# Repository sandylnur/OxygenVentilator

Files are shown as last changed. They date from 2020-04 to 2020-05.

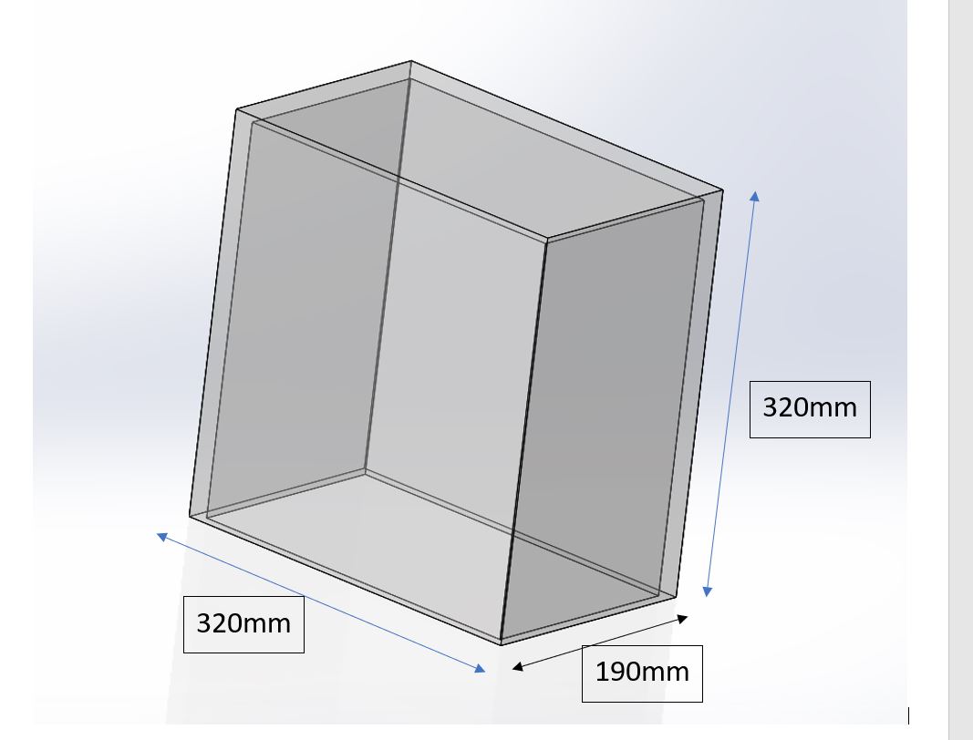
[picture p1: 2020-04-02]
ProtoType Deisgn/Casing Design & Dimensions/Approximate Require Casing Size.JPG

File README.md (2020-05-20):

# OxygenVentilator
The following is an initiative to cope for the lack of Oxygen Ventilator for the Covid-19 Outbreak. This is an Arduino based project for controlling an actuator/stepper motor.

Link to Doc
https://docs.google.com/document/d/1eH-yhwD40MbvZu5IXgRE8FFyR08LFT27kJvr4FsMqDs/edit?usp=sharing

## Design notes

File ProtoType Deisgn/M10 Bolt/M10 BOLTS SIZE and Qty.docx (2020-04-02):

# For Connection

M10 Bolts + Nuts will be used

Length(approximate) | Qty
43mm | 1
34mm | 1
84mm | 3

Washer for M10, Qty =6

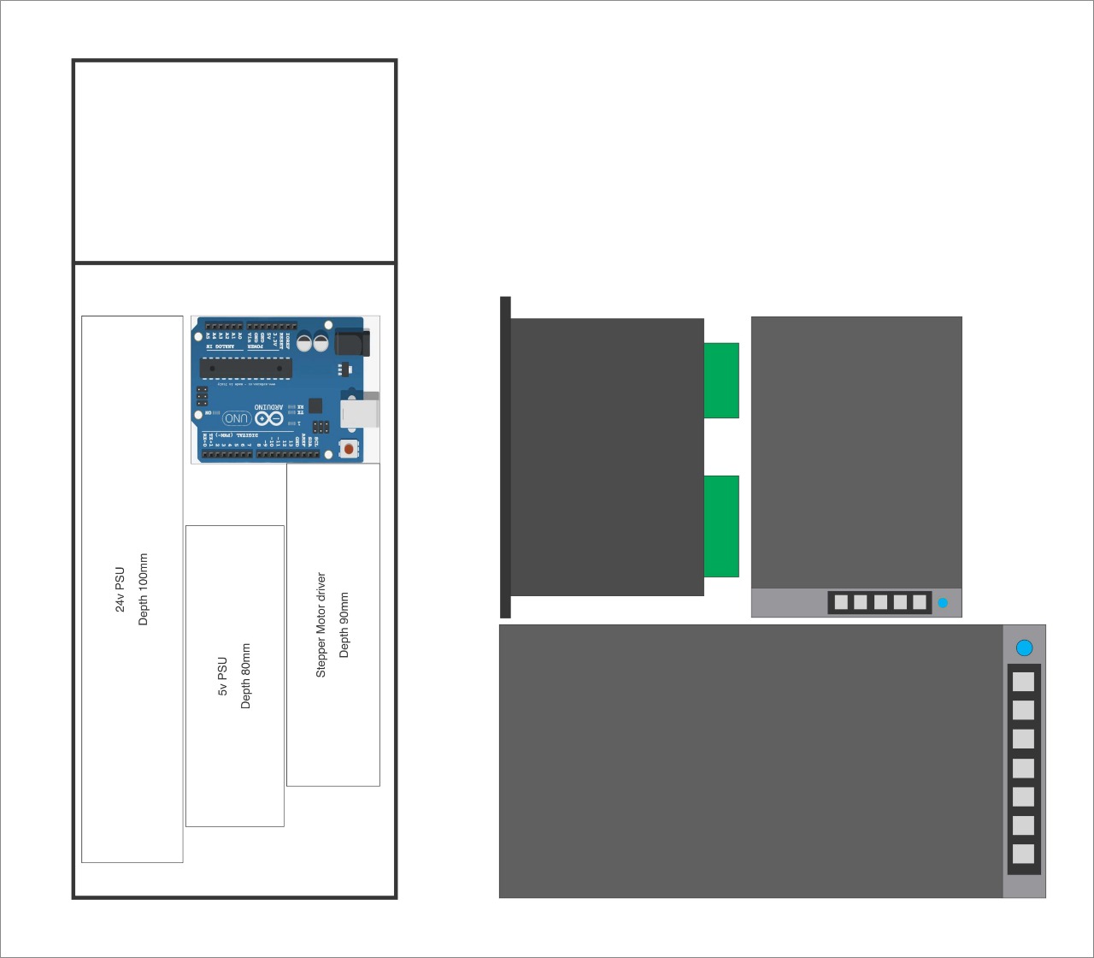
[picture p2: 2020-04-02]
ProtoType Deisgn/Casing Design & Dimensions/Electronics Placement Schematic.jpg

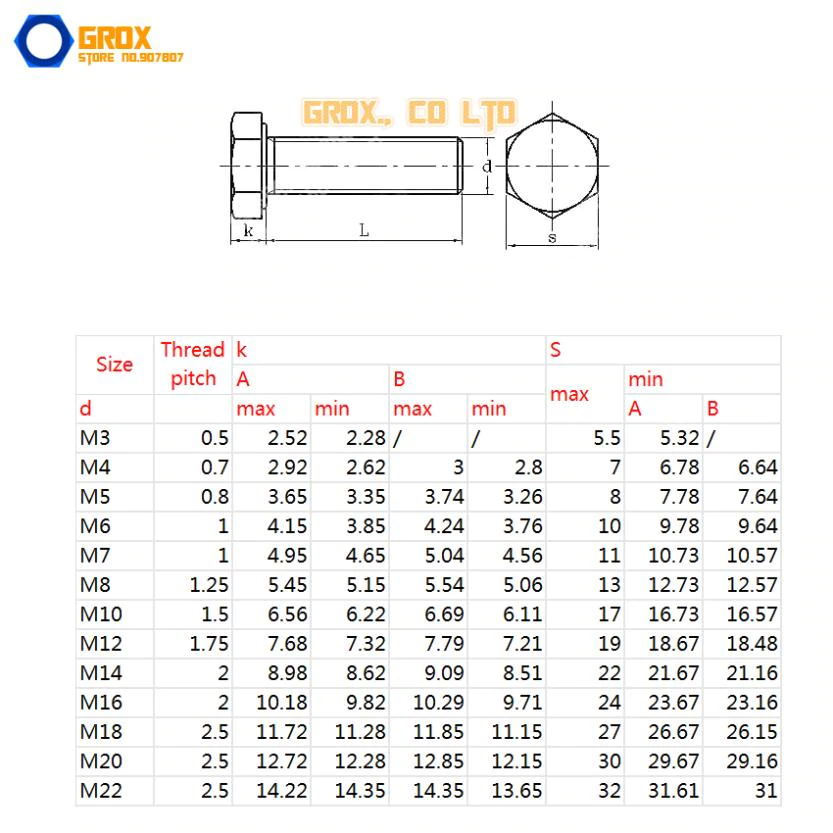
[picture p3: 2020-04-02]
ProtoType Deisgn/M10 Bolt/m10 bolt Dimension.webp

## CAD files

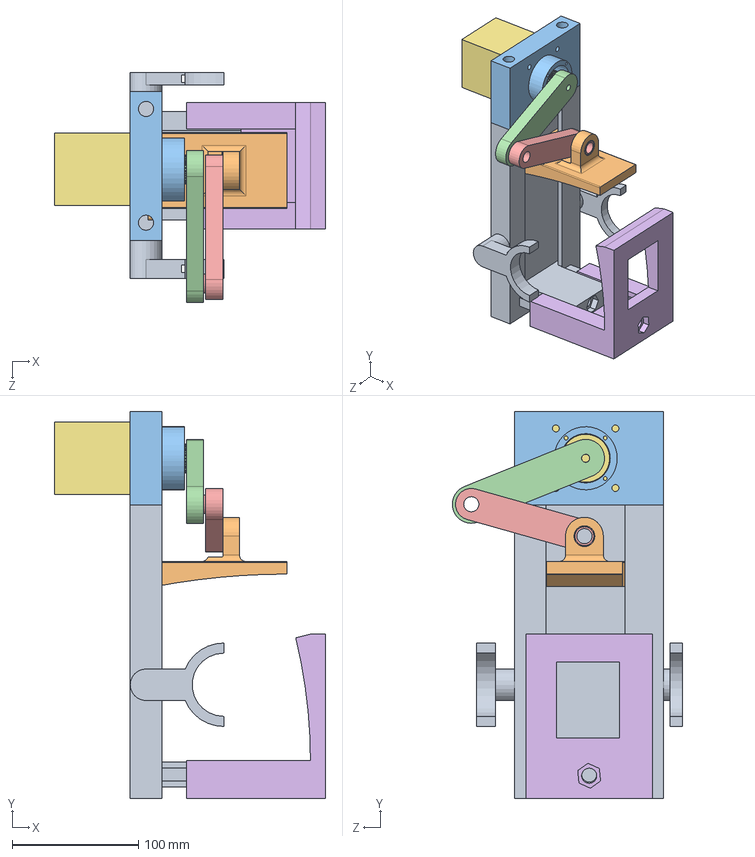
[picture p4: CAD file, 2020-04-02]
ProtoType Deisgn/Solidworks Parts/Assembly V1.SLDASM
214.6 x 306.2 x 182.3 mm
sliding prt 1 enba V2
press
Nema 23 Head
cam nema 23
rod 4
sliding part 2
nema 23

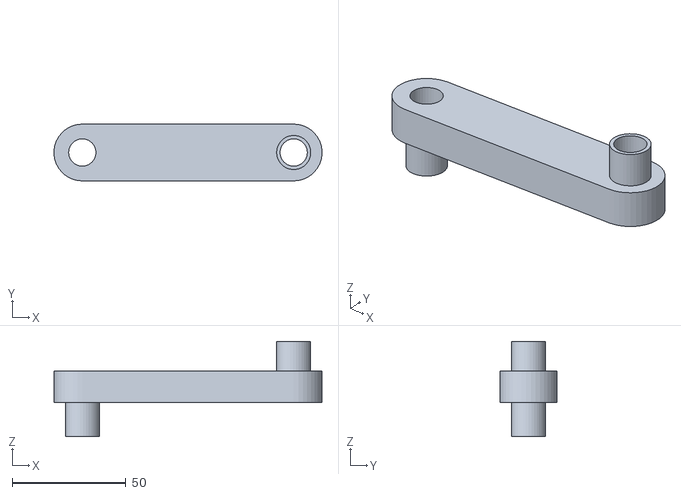
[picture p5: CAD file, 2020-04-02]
ProtoType Deisgn/Solidworks Parts/STL files for Printing/link 2.STL
117.9 x 25.0 x 42.0

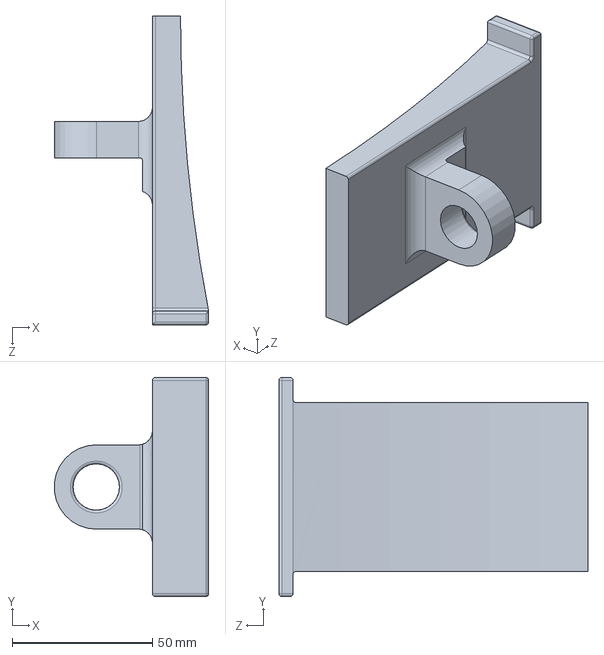
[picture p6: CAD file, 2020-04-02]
ProtoType Deisgn/Solidworks Parts/press.SLDPRT
54.9 x 78.0 x 110.0 mm

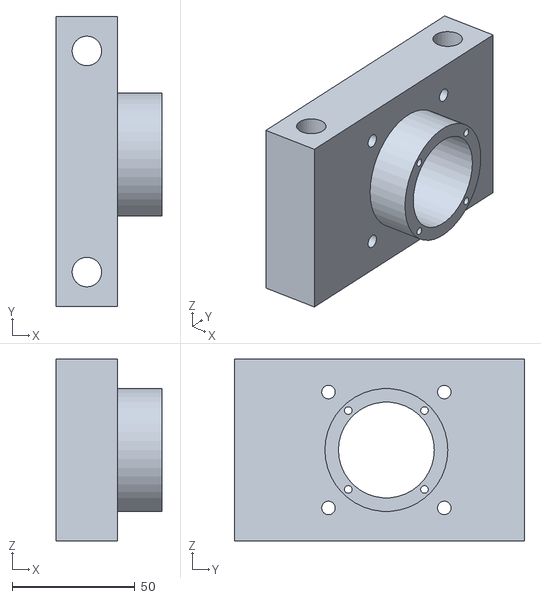
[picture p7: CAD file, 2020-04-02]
ProtoType Deisgn/Solidworks Parts/STL files for Printing/Nema 23 HeadModule.STL
43.0 x 118.0 x 74.0

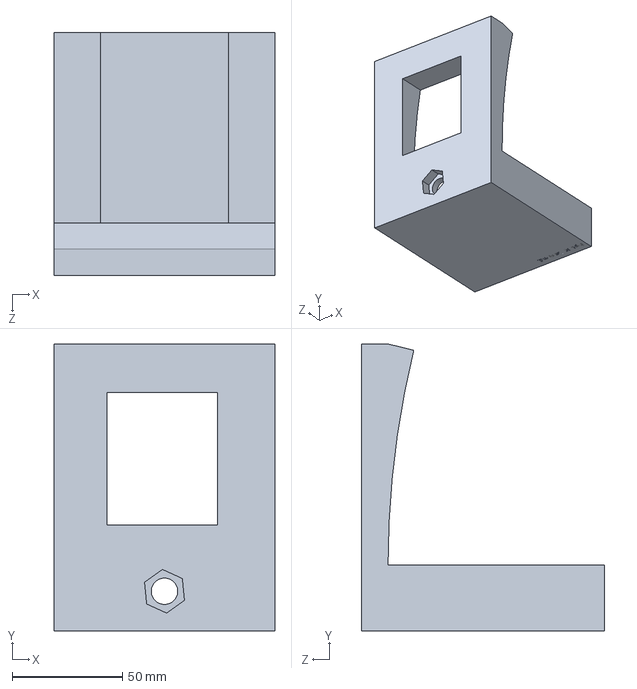
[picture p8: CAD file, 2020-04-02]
ProtoType Deisgn/Solidworks Parts/Clamp Slide.SLDPRT
100.0 x 130.0 x 110.0 mm

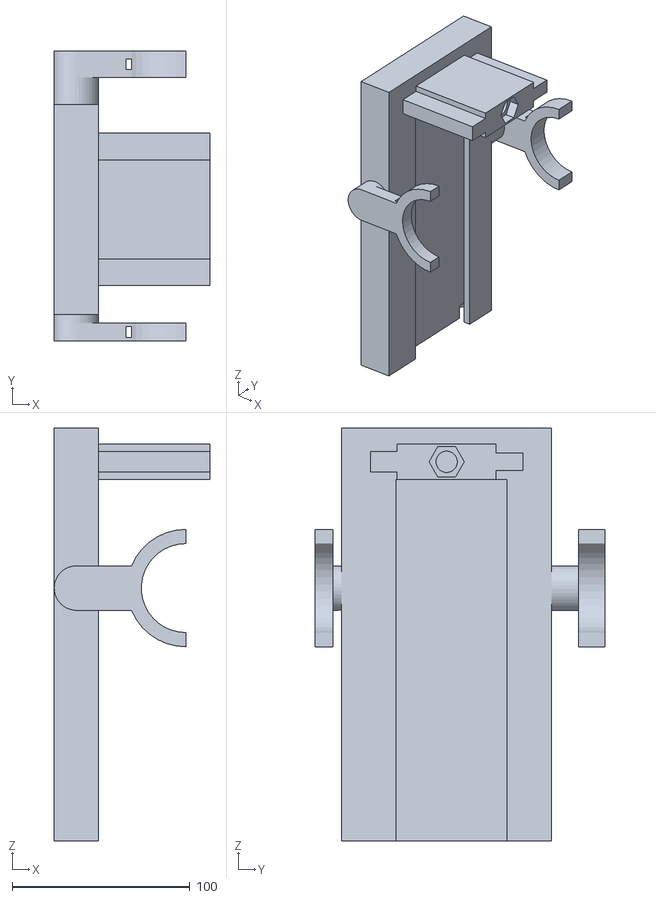
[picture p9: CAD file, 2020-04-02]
ProtoType Deisgn/Solidworks Parts/STL files for Printing/Mounting Plate.STL
87.5 x 163.0 x 232.2

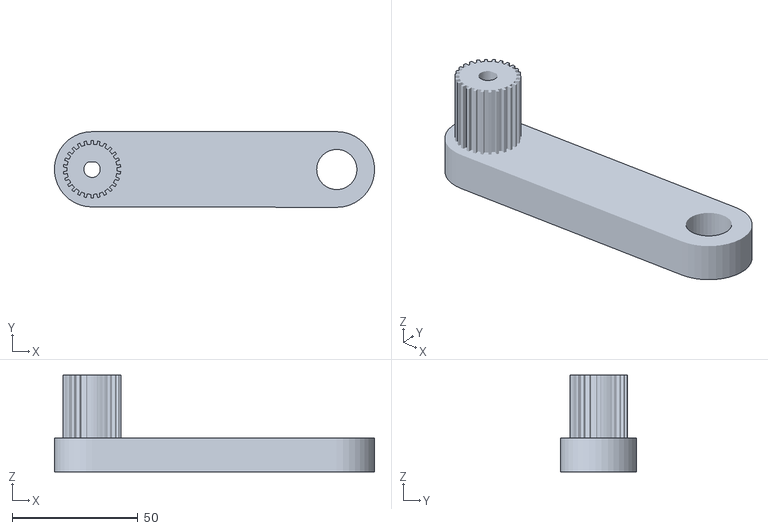
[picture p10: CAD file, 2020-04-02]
ProtoType Deisgn/Solidworks Parts/STL files for Printing/cam nema 23 ,link1.STL
127.5 x 30.2 x 38.5

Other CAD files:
ProtoType Deisgn/Solidworks Parts/STL files for Printing/press.STL
ProtoType Deisgn/Solidworks Parts/Nema 23 HeadModule.SLDPRT
ProtoType Deisgn/Solidworks Parts/link 2.SLDPRT
ProtoType Deisgn/Solidworks Parts/STL files for Printing/Clamp Slide.STL
ProtoType Deisgn/Solidworks Parts/Mounting Plate.SLDPRT
ProtoType Deisgn/Solidworks Parts/cam nema 23 ,link1.SLDPRT

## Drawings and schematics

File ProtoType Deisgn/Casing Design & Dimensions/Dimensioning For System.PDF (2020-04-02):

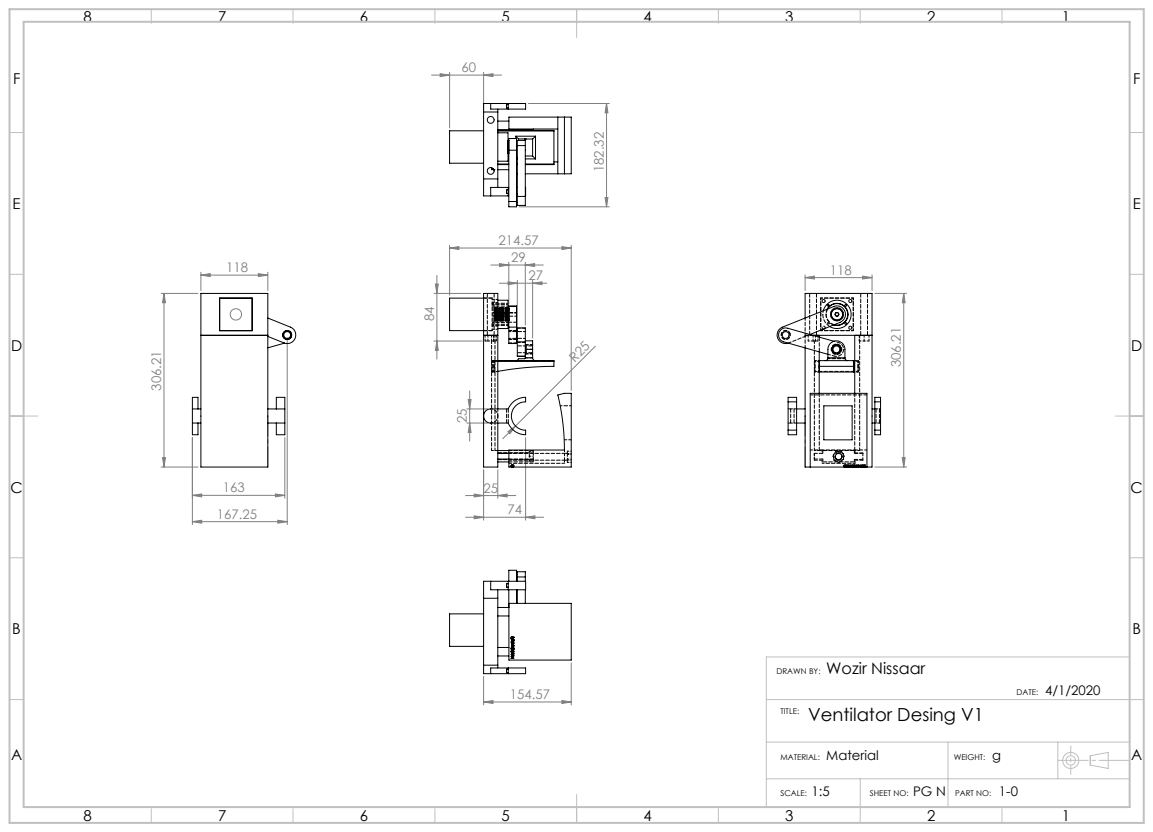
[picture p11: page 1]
DRAWN BY:; SCALE:; SHEET NO:; PART NO:; Wozir Nissaar; Ventilator Desing V1

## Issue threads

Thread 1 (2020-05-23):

Motor Burning

sandylnur, 2020-05-23:
Motor currently burning while not hitting limit switch.

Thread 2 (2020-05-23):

Motor Issue

sandylnur, 2020-05-23:

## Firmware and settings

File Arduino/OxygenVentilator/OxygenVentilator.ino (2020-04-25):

/**
 * OxygenVentilator Project - Rack and Pinion
 * Version          : 0.4
 * Author           : Project Volunteers
 * Date Created     : 04/04/2020 (DD :MM :YYYY)
 * Date Modified    : 25/04/2020
 **/

#include <LiquidCrystal_I2C.h>
#include <Wire.h>

// #define fomula_debug // debugging message for formulae verification (uncomment to see the debug message on serial monitor) 

// push button variables
  int pushButtonPin = 3;
  int lastButtonState = 1;
  long unsigned int lastPress;
  volatile int buttonFlag;
  int debounceTime = 50;

// ventilator variables
  int ventStatus = 0;

// presets
  #define idle 0    // to be taken out if not necessary
  #define IE1to2 2
  #define IE1to3 3
  #define IE1to1 1
  #define IE2to1 0.5

// potentiometer connected pins
  const int potOnePin   = A0; // potentiometer one
  const int potTwoPin   = A1; // potentiometer two
  const int potThreePin = A2; // potentiometer three

// led light status pin
  const int ledPin = 13;
  const int sendSignal = 11;

// parameters for prototype 3, values to be calibrated and change accordingly
  float actuationDistance = 50;     // value in mm
  float pionRadius        = 29.75;  // value in mm
  float shaftRadius       = 7.88;   // value in mm
  const int stepsPerRevolution = 200;    

// buzzer pin
  const int piezoPin = 5;

// initialize the library by associating any needed LCD interface pin
// with the arduino pin number it is connected to
// const int rs = 13, en = 12, d4 = 11, d5 = 10, d6 = 9, d7 = 8;
// LiquidCrystal lcd(rs, en, d4, d5, d6, d7);
  LiquidCrystal_I2C lcd(0x3F, 16, 2);

// variables for display output
  String bpmLCD;
  String rvLCD;
  String ieLCD;

// declare pins for motor
  const int stepPin = 10; //PUL -Pulse 10
  const int dirPin  = 9;  //DIR -Direction 9
  const int enPin   = 8;  //ENA -Enable 8

// declare limit switch pin
  const int limitSwitch = 2;
  int bootCheck         = 0;

// varibles for starting and looping position of motor
  int inhalationMSteps, inhalationMS, exhalationMSteps, exhalationMS;

void setup() {
  // put your setup code here, to run once:

  // start serial
  #ifdef fomula_debug
    Serial.begin(9600);
    while (!Serial) {
        ; // wait for serial port to connect. Needed for native USB
    }
  #endif
  
  // setup display
    setupDisplay();
  
  // setup pin modes
    pinMode(pushButtonPin, INPUT_PULLUP);
    pinMode(limitSwitch, INPUT);
    pinMode(ledPin, OUTPUT);
    pinMode(sendSignal, OUTPUT);
  
  // setup for push button, use 3rd param as LOW, HIGH, CHANGE, FALLING, RISING
    attachInterrupt(digitalPinToInterrupt(pushButtonPin), pushButtonISR, CHANGE);

  // setup pins for motor, as outputs
    pinMode(stepPin, OUTPUT); 
    pinMode(dirPin, OUTPUT);
    pinMode(enPin, OUTPUT);

  // boot position calibration protocol 
    bootProtocol();
}

void loop() {
  // put your main code here, to run repeatedly:
  // check if button is pressed
    checkButton();

  // if ventilator started do
    ventilatorStarted();
    
  // update display in real time only if ventilator is not running
    updateDisplay();
}

// boot protocol to zero position of stepper
void bootProtocol() {
  digitalWrite(enPin, LOW);
  digitalWrite(sendSignal, LOW);
  
  if (bootCheck == 0){
    while (digitalRead(limitSwitch) == 0){
      runMotor(16, 2500, false); // motorMicroSteps, motorMicroSeconds, Clock-Wise -> TRUE, Anti-Clock-Wise -> FALSE
    }
    bootCheck = 1;
  }

  digitalWrite(enPin, HIGH);
  digitalWrite(sendSignal, HIGH);
}

// push button controls
#pragma region 
void pushButtonISR (){
  buttonFlag = 1;
  //Serial.println("ISR");
  //checkButton();
  buzzer();
}

void checkButton(){
  if((millis() - lastPress) > debounceTime && buttonFlag){ 
    lastPress = millis();
    if(digitalRead(pushButtonPin) == 0){ // && lastButtonState == 1
      Serial.println("Button Triggered");
      switch (ventStatus) {
        case 0:
          startVentilator();
          ventStatus = 1;
        break;

        case 1:
          stopVentilator();
          ventStatus = 0;
        break;
      }
      lastButtonState = 0;
    }
    
    else if(digitalRead(pushButtonPin) == 1 && lastButtonState == 0){
      lastButtonState = 1;
    }
    buttonFlag = 0;
  }
}
#pragma endregion

// ventilator start, stop procedures
#pragma region 
// function to start ventilator
void startVentilator(){
  // write code to start ventilator
    Serial.println("Starting ventilator");
    buzzer();

  // set led status ON
    digitalWrite(ledPin, HIGH);
    
  // inhalation, clockwise
    float repirationDuration        = 60 / getPotInput("bpm_in");
    float inhalationTime            = repirationDuration / (1 + getPotInput("presets_in"));
    float inhalationRPM             = (actuationDistance * getPotInput("rv_in") * 60 * 7) / (inhalationTime * 44 * (pionRadius - shaftRadius) * (100));
    float inhalationNumberOfSteps   = (inhalationRPM * inhalationTime * stepsPerRevolution) / 60; // 400 -> stepsPerRevolution

  // exhalation, anti-clockwise
    float exhalationRPM             = inhalationRPM / getPotInput("presets_in");
    float exhalationNumberOfSteps   = inhalationNumberOfSteps;

  // inhalation, conversion for stepper
    float numOfInhaMicroSteps = inhalationNumberOfSteps * 16;
    int inhalationMotorMicroSteps = int(numOfInhaMicroSteps); // 3200

    float inhalFactorDelMicroSec = (inhalationTime * 1000000) / (2 * inhalationMotorMicroSteps);
    int inhalFacDelMicroSec = int(inhalFactorDelMicroSec);

  // exhalation, conversion for stepper
    int exhalationMotorMicroSteps = inhalationMotorMicroSteps;

    float exhalFactorDelMicroSec = ((inhalationTime * getPotInput("presets_in")) * 1000000) / (2 * inhalationMotorMicroSteps);
    int exhalFacDelMicroSec = int(exhalFactorDelMicroSec);

  //double speed_rpm, int N_step, bool Direction
  #ifdef fomula_debug
    Serial.println("Potentiometer Values");
    Serial.println(getPotInput("bpm_in"));
    Serial.println(getPotInput("rv_in"));
    Serial.println(getPotInput("presets_in"));

    Serial.println();

    Serial.println("Inhalation");
    Serial.println(inhalationMotorMicroSteps);
    Serial.println(inhalFacDelMicroSec);

    Serial.println();

    Serial.println("Exhalation");
    Serial.println(exhalationMotorMicroSteps);
    Serial.println(exhalFacDelMicroSec);
  #endif

  inhalationMSteps = inhalationMotorMicroSteps;
  inhalationMS     = inhalFacDelMicroSec;
  exhalationMSteps = exhalationMotorMicroSteps;
  exhalationMS     = exhalFacDelMicroSec;

  // start motor
    digitalWrite(enPin, LOW);
    digitalWrite(sendSignal, LOW);
}

void ventilatorStarted(){
  if (ventStatus == 1){
    // run automated procedure for motor
    // motor run clockwise
    runMotor(inhalationMSteps, inhalationMS, true); // motorMicroSteps, motorMicroSeconds, Clock-Wise -> TRUE, Anti-Clock-Wise -> FALSE
    // motor run anti-clockwise
    runMotor(exhalationMSteps, exhalationMS, false); // motorMicroSteps, motorMicroSeconds, Clock-Wise -> TRUE, Anti-Clock-Wise -> FALSE
  }
}

void stopVentilator(){
  // write code to stop ventilator
    Serial.println("Stopping ventilator");
    buzzer();

  // set led status off
    digitalWrite(ledPin, LOW);

  // stop motor
    digitalWrite(enPin, HIGH);
    digitalWrite(sendSignal, HIGH);
}
#pragma endregion

// inputs and outputs procedures
#pragma region 
// input for potentiometer one, two, three
float getPotInput(String potentiometer) {
    if (potentiometer == "bpm_in") {
      int potValueOne = analogRead(potOnePin);
      int potMappedValueOne = map(potValueOne, 0, 1023, 10, 31); // return 10 to 30
      return potMappedValueOne;
    }

    else if (potentiometer == "rv_in") {
      int potValueTwo = analogRead(potTwoPin);
      int potMappedValueTwo = map(potValueTwo, 0, 1023, 0, 101); // return 0 to 100
      //float fractionOfMaxVol = potMappedValueTwo / 100;
      return potMappedValueTwo;
    }

    else if (potentiometer == "presets_in") {
      int potValueThree = analogRead(potThreePin);
      int potMappedValueThree = map(potValueThree, 0, 1023, 0, 99);
      int potDiscreteValue = potMappedValueThree / 20;
      
      // enter switch case
      switch(potDiscreteValue)
      {
        case 0:
          return IE1to1;
          break;
        case 1:
          return IE1to1;
          break;
        case 2:
          return IE1to2;
          break;
        case 3:
          return IE1to3;
          break;
        case 4:
          return IE2to1;
          break;
        default:
          // Serial.println("Potentiometer 3, Error!");
          break;
      }
    }
}

// output function to call buzzer
void buzzer(){
    tone(piezoPin, 1000, 500);
}

// output function to display
void setupDisplay(){
  // set up the LCD's number of columns and rows:
  // lcd.begin(16, 2);
      lcd.init();
      lcd.backlight();
    
  // Print a message to the LCD.
    lcd.setCursor(0,0) ;
    lcd.print("BPM   RV%    I:E");
}

void updateDisplay(){
  if (ventStatus == 0){
    bpmLCD = String(int(getPotInput("bpm_in")));
    if (int(getPotInput("rv_in")) >= 100){
      rvLCD  = "  " + String(int(getPotInput("rv_in")));
    } else if (int(getPotInput("rv_in")) < 10) {
      rvLCD  = "    " + String(int(getPotInput("rv_in")));
    } else if (int(getPotInput("rv_in")) < 100){
      rvLCD  = "   " + String(int(getPotInput("rv_in")));
    }

    if (getPotInput("presets_in") == IE1to1){
      ieLCD = "1:1";
    } else if (getPotInput("presets_in") == IE1to2){
      ieLCD = "1:2";
    } else if (getPotInput("presets_in") == IE1to3){
      ieLCD = "1:3";
    } else if (getPotInput("presets_in") == IE2to1){
      ieLCD = "2:1";
    }
    
    lcd.setCursor(0,1);
    String toPrint = " " + bpmLCD + " " + rvLCD + "    " + ieLCD;
    lcd.print(toPrint);
  }
}

// motorMicroSteps, motorMicroSeconds, Clock-Wise -> FALSE, Anti-Clock-Wise -> TRUE
void runMotor(int motorMicroSteps, int motorMicroSeconds, bool direction) {
    if (direction == true){
      digitalWrite(dirPin, HIGH);
    } else if (direction == false){
      digitalWrite(dirPin, LOW);
    }

    if (bootCheck == 1){
      if (direction == true) {
        // inhalation normally
        for(int x = 0; x < (motorMicroSteps); x++){
          digitalWrite(stepPin, HIGH); 
          delayMicroseconds(motorMicroSeconds);
          digitalWrite(stepPin, LOW);
          delayMicroseconds(motorMicroSeconds);
        }
      } else if (direction == false){
        // exhalation normally then zero-in
          for(int x = 0; x < (motorMicroSteps); x++){
            digitalWrite(stepPin, HIGH); 
            delayMicroseconds(motorMicroSeconds);
            digitalWrite(stepPin, LOW);
            delayMicroseconds(motorMicroSeconds);
          }
          while (digitalRead(limitSwitch) == 0){
            runMotor(1, motorMicroSeconds, false);
          }
      }
    } else {
        // boot protocol motor function
          for(int x = 0; x < (motorMicroSteps); x++){
            digitalWrite(stepPin, HIGH); 
            delayMicroseconds(motorMicroSeconds);
            digitalWrite(stepPin, LOW);
            delayMicroseconds(motorMicroSeconds);
          }
    }
}
#pragma endregion

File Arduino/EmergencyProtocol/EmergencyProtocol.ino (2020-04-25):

/**
 * Emergency Protocol Code
 * Version          : 0.3
 * Author           : Sandyl Nursigadoo, Tavish Hookoom
 * Date Created     : 12/04/2020 (DD :MM :YYYY)
 * Date Modified    : 25/04/2020
 **/

#define Debug // debugging message for emergency verification (uncomment to see the debug message on serial monitor)

// connected arduino pins
const int emergencyButtonPin = 2;
const int limitSwitchPin     = 3;
const int relaySwitchPin     = 9;
const int buzzerPin          = 10;
const int ventEnablePin      = A0;

// flag for status of emergency scenario
bool initializationCheck    = false;
bool ventStatus      = false;
bool emergencyMotor  = false;
bool emergencyToggle = false;

// calibration time for maximum time for limit switch to be trigger
const int timeCalibration       = 7000;   // maximum inhalation plus exhalation time
const int bootTimeCalibration   = 14000;  // maximum zero-in time
unsigned long counterLastPress;

// flag for if limit switch was toggled
bool limitSwitchFlag;

void setup() {
  // put your setup code here, to run once:
  // emergency button
  pinMode(emergencyButtonPin, INPUT);
  attachInterrupt(digitalPinToInterrupt(emergencyButtonPin), EmergencyISR, FALLING);

  // limit switch
  pinMode(limitSwitchPin, INPUT);
  attachInterrupt(digitalPinToInterrupt(limitSwitchPin), LimitSwitchISR, CHANGE);

  // relay switch
  pinMode(relaySwitchPin, OUTPUT);
  digitalWrite(relaySwitchPin, HIGH);

  // buzzer
  pinMode(buzzerPin, OUTPUT);

  // ventilator status from mainboard
  pinMode(ventEnablePin, INPUT);

  #ifdef Debug
    Serial.begin(9600);
    while (!Serial) {
      ; // wait for serial port to connect. Needed for native USB
    }
  #endif
}

void loop() {
  #pragma Emergency Protocol
    if (emergencyToggle == true || emergencyMotor == true) {
      // whenever emergency button or and error with limit switch identifying an issue on motor
      digitalWrite(relaySwitchPin, LOW);
      digitalWrite(buzzerPin, HIGH);
      #ifdef Debug
        Serial.println("Emergency Occured");
      #endif
    }

    if (digitalRead(emergencyButtonPin) == HIGH && emergencyToggle == true) {
      // reset when evergency button is released
      digitalWrite(relaySwitchPin, HIGH);
      digitalWrite(buzzerPin, LOW);
      emergencyToggle = false;
      emergencyMotor = false;
      ventStatus = false;
      initializationCheck = false;
    }
  #pragma endregion

  if (initializationCheck == false) {    
    #ifdef Debug
      Serial.println("Initializing Procedure Started");
    #endif
    
    while(digitalRead(ventEnablePin) == LOW) {
      CheckMotorRunning(bootTimeCalibration);
      if(emergencyMotor == true){
        break;
      }
    } 
    initializationCheck = true;
    #ifdef Debug
      Serial.println("Initializing Procedure Completed");
    #endif
  }

  if (initializationCheck == true) {
    CheckMotorRunning(timeCalibration);
  }

}

void CheckMotorRunning(int _timeCheck) {
    if (digitalRead(ventEnablePin) == LOW && ventStatus == false) {
      ventStatus = true;
      counterLastPress = millis();
      #ifdef Debug
        Serial.println("Ventilator Operational");
      #endif
    } else if (digitalRead(ventEnablePin) == HIGH && ventStatus == true) {
      ventStatus = false;
      #ifdef Debug
        Serial.println("Ventilator Not Operational");
      #endif
    }

    if (ventStatus == true && emergencyMotor == false) {
      if (limitSwitchFlag == 1) {
        #ifdef Debug
          Serial.println("Tap");
        #endif
        counterLastPress = millis();
        limitSwitchFlag = 0;
      }

      int pinState = digitalRead(limitSwitchPin);

      if (millis() - counterLastPress >= _timeCheck) {

        Serial.println(millis() - counterLastPress);
        emergencyMotor = true;
        if (pinState == HIGH) {
          #ifdef Debug
            Serial.println("Error! Constant High!!");
          #endif
          emergencyMotor = true;
        } else {
          #ifdef Debug
            Serial.println("Error! Missed Limit Switch!!");
          #endif
          emergencyMotor = true;
        }
      }
    }
}

void EmergencyISR() {
  digitalWrite(relaySwitchPin, LOW);
  digitalWrite(buzzerPin, HIGH);
  emergencyToggle = true;
}

void LimitSwitchISR() {
  limitSwitchFlag = 1;
}

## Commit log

2020-04-02 Added Prototype Design by Scarface
    [Assembly V1.SLDASM, Clamp Slide.SLDPRT, Clamp Slide.STL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]
2020-04-08 Latest Update for Prototype 3
2020-04-08 Revert "Latest Update for Prototype 3"
    This reverts commit 96a15c6cab43bf27b12d47a8ea980ad5b5ab82d6.
2020-04-08 Major Updates to Code
    [Assembly V1.SLDASM, Clamp Slide.SLDPRT, Clamp Slide.STL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]
2020-04-11 RealTime Update Insfrastructure
    [Assembly V1.SLDASM, Clamp Slide.SLDPRT, Clamp Slide.STL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]
2020-04-12 Update for Emergency Protocol TS
    [Assembly V1.SLDASM, Clamp Slide.SLDPRT, Clamp Slide.STL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]
2020-04-16 Working Prototype Update
2020-04-16 Project Circuit Design Added
    [Assembly V1.SLDASM, Clamp Slide.SLDPRT, Clamp Slide.STL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]
2020-04-21 LCD Over I2C Code Update
2020-04-21 Revert "Project Circuit Design Added"
    This reverts commit a1b68f3631a0f191399292cb21bd8dc83671a75a.
    [Assembly V1.SLDASM, Clamp Slide.SLDPRT, Clamp Slide.STL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]
2020-04-21 Code for LCD i2C Update
2020-04-23 Pin Changes
2020-04-25 Emergency Zero-In Fails Added, Small Fixes Main
    [Emergency_v2.ino, OxygenVentilator.ino]
2020-04-26 Cleaning Directories
    [Assembly V1.SLDASM, Clamp Slide.SLDPRT, Clamp Slide.STL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]
